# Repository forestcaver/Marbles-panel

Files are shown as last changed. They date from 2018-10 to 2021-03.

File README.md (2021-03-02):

# Marbles-Panel

1. My version of the marbles panel - bitmap, eagle files, gerbers
2. My spreadsheet to calibrate marbles and my version of settings.cc which includes my calibration data for my two modules.
3. Calibration document written by Bu Ma from some rough notes I sent - his are very clear instructions ! (Reproduced here by kind permission of Bu Ma !)
4. NOTE: When flashing the module make sure to erase flash first.
5. Added a mic803 supervisor, moved recom to the back of the pcb so it doesnt clash with the switch

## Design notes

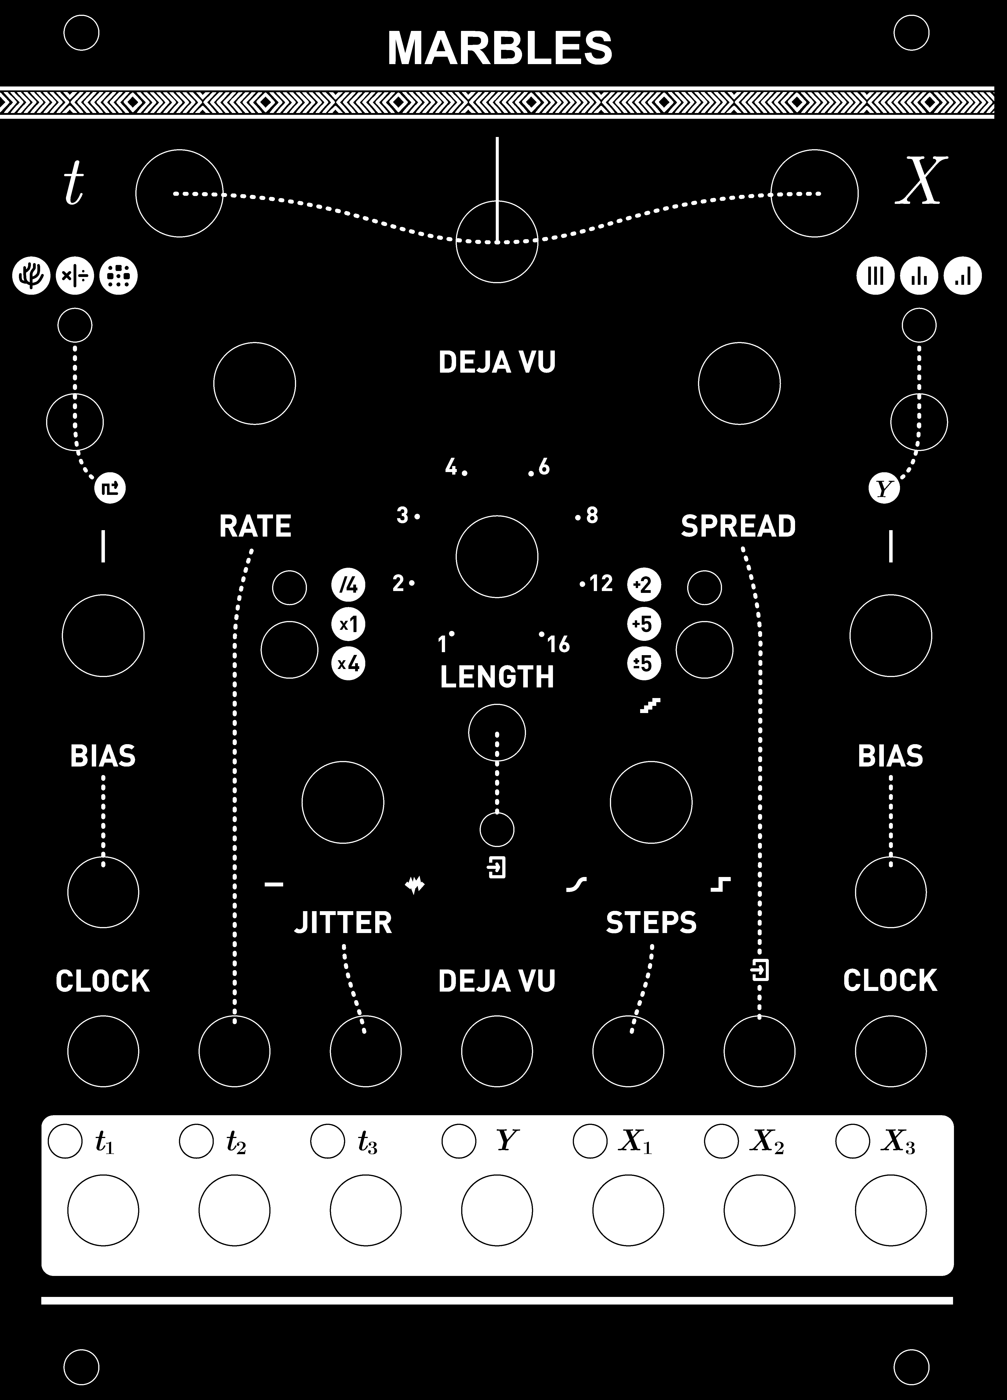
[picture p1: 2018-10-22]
marbles_v70_AJH3.bmp

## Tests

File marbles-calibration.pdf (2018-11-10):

## Marbles Calibration

Part 1: setting the module to output quantized voltages 1V and 3V.

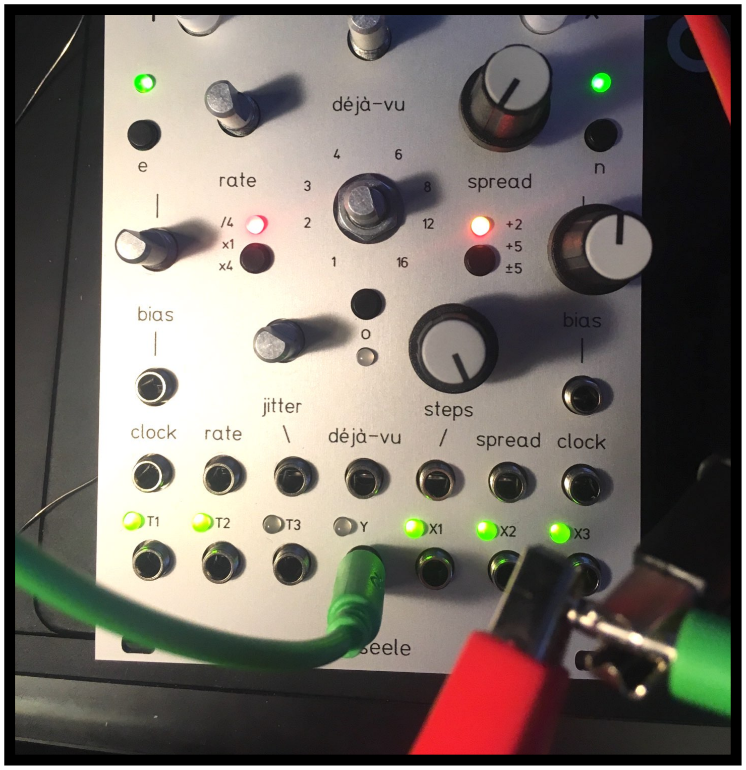
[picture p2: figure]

1. Connect the CV output X1 to a high count (ie 50000 count) multimeter (fig.1)
2. Set the voltage range (J) to +5V (orange LED).
3. Set (E) and (N) to green.
4. Turn the « Spread » knob fully counter-clockwise
5. Turn the « Steps » knob fully clockwise
6. Turn « bias » to select the octave, you need to find the closest value to 1V (You will probably find a value between 0.91 and 0.99). Then do the same for
3V.
7. Write down these values in
the corresponding cells of the spreadsheet (1V and 3V) and do the same thing for
the next CV outputs X2 and
X3.

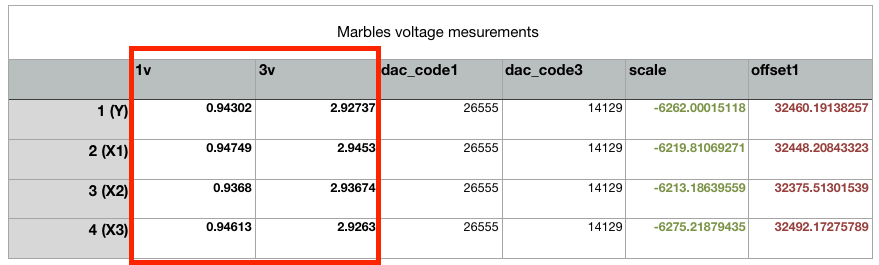
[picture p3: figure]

8. For the Y output : hold down the (N) button and turn the « Spread » knob fully counter-clockwise and the « Steps » knob fully clockwise. You will probably have to adjust the « rate » in order to « stabilize » this CV output while you read the voltage value.

Part 2: copying the voltage measurements to settings.cc, compiling and uploading the firmware.

1. Open the file named settings.cc in an editor. You will find the file in Mutable-dev-environment -> eurorack-modules -> Marbles

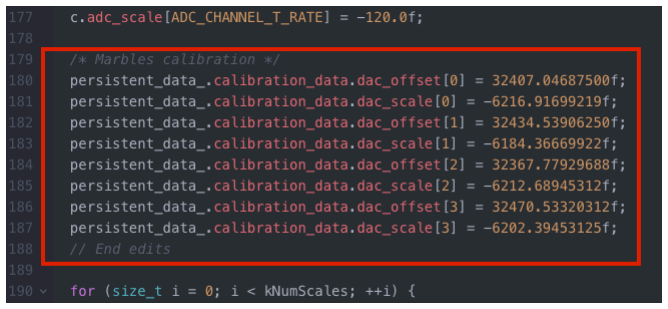
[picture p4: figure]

2. Copy and paste the values of
Scale and Offset from the
spreadsheet to settings.cc
(line 179). Don’t forget the « f » and make sure the
separator is a dot. [O] is Y
[1] is X1 etc.

### 3. Save the file, compile the

firmware and upload it to
the module.

Part 3: ADC calibration.

To calibrate the adc, long-press the rate and spread buttons. Feed 1v into rate input, press one of the two buttons, feed in 3v, press button, feed 1v into spread cv, press button and then feed 3v into spread cv, press button and the calibration is done.

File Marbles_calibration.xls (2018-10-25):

Table 1
 | 1v | 3v | dac_code1 | dac_code3 | scale | offset1 | offset2
1 | 0.94302 | 2.92737 | 26555 | 14129 | -6262.000151 | 32460.19138 | 32460.19138
2 | 0.94749 | 2.9453 | 26555 | 14129 | -6219.810693 | 32448.20843 | 32448.20843
3 | 0.9368 | 2.93674 | 26555 | 14129 | -6213.186396 | 32375.51302 | 32375.51302
4 | 0.94613 | 2.9263 | 26555 | 14129 | -6275.218794 | 32492.17276 | 32492.17276
 | 1v | 3v | dac_code1 | dac_code3 | scale | offset1 | offset2
1 | 0.94131 | 2.94005 | 26555 | 14129 | -6216.916657 | 32407.04582 | 32407.04582
2 | 0.95071 | 2.95997 | 26555 | 14129 | -6184.366384 | 32434.53896 | 32434.53896
3 | 0.93563 | 2.93573 | 26555 | 14129 | -6212.689366 | 32367.77855 | 32367.77855
4 | 0.95375 | 2.95717 | 26555 | 14129 | -6202.393906 | 32470.53319 | 32470.53319

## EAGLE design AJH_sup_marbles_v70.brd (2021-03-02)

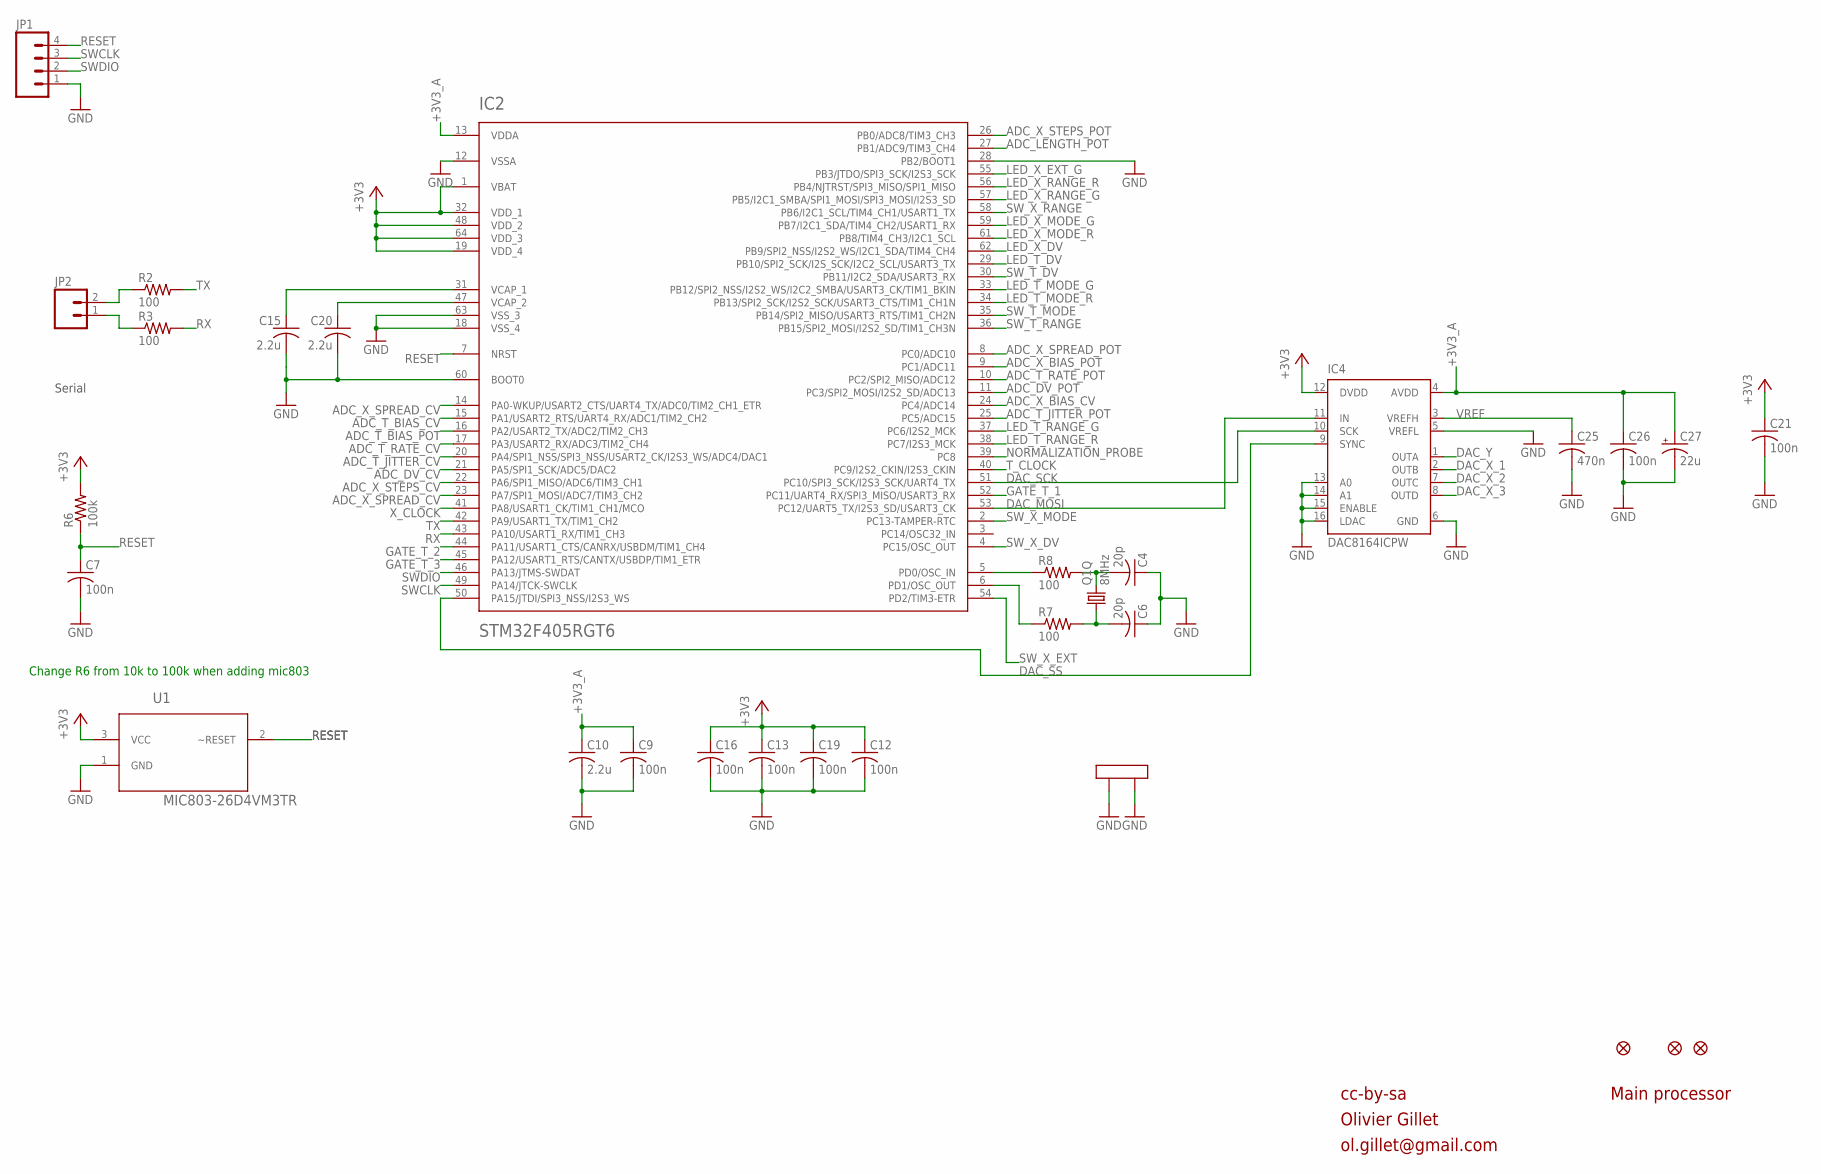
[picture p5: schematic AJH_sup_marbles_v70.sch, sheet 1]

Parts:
C4, C6: 20p; C0402
C7, C9, C12, C13, C16, C19, C21, C26: 100n; C0402
C10, C15, C20: 2.2u; C0805
C25: 470n; C0402
C27: 22u; PANASONIC_C
F1, F2, F3: FIDUCIAL1X2; FIDUCIAL-1X2
IC2: STM32F405RGT6; TQFP-10X10-64
IC4: DAC8164ICPW; SOP65P640X110-16N
JP1: M04PTH; 1X04
JP2: M02PTH; 1X02
Q1: 8MHz; CTS406
R2, R3, R7, R8: 100; R0402
R6: 100k; R0402
U1: MIC803-26D4VM3TR; SOT95P232X110-3N

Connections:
+3V3: C12.1, C13.1, C16.1, C19.1, C21.1, IC2.1 (VBAT), IC2.19 (VDD_4), IC2.32 (VDD_1), IC2.48 (VDD_2), IC2.64 (VDD_3), IC4.12 (DVDD), R6.2, U1.3 (VCC); also elsewhere on the board
+3V3_A: C9.1, C10.1, C26.1, C27.+, IC2.13 (VDDA), IC4.4 (AVDD); also elsewhere on the board
ADC_DV_CV: IC2.21 (PA5/SPI1_SCK/ADC5/DAC2); also elsewhere on the board
ADC_DV_POT: IC2.11 (PC3/SPI2_MOSI/I2S2_SD/ADC13); also elsewhere on the board
ADC_LENGTH_POT: IC2.27 (PB1/ADC9/TIM3_CH4); also elsewhere on the board
ADC_T_BIAS_CV: IC2.15 (PA1/USART2_RTS/UART4_RX/ADC1/TIM2_CH2); also elsewhere on the board
ADC_T_BIAS_POT: IC2.16 (PA2/USART2_TX/ADC2/TIM2_CH3); also elsewhere on the board
ADC_T_JITTER_CV: IC2.20 (PA4/SPI1_NSS/SPI3_NSS/USART2_CK/I2S3_WS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); also elsewhere on the board
ADC_T_JITTER_POT: IC2.25 (PC5/ADC15); also elsewhere on the board
ADC_T_RATE_CV: IC2.17 (PA3/USART2_RX/ADC3/TIM2_CH4); also elsewhere on the board
ADC_T_RATE_POT: IC2.10 (PC2/SPI2_MISO/ADC12); also elsewhere on the board
ADC_X_BIAS_CV: IC2.24 (PC4/ADC14); also elsewhere on the board
ADC_X_BIAS_POT: IC2.9 (PC1/ADC11); also elsewhere on the board
ADC_X_SPREAD_CV: IC2.14 (PA0-WKUP/USART2_CTS/UART4_TX/ADC0/TIM2_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), IC2.23 (PA7/SPI1_MOSI/ADC7/TIM3_CH2); also elsewhere on the board
ADC_X_SPREAD_POT: IC2.8 (PC0/ADC10); also elsewhere on the board
ADC_X_STEPS_CV: IC2.22 (PA6/SPI1_MISO/ADC6/TIM3_CH1); also elsewhere on the board
ADC_X_STEPS_POT: IC2.26 (PB0/ADC8/TIM3_CH3); also elsewhere on the board
DAC_MOSI: IC2.53 (PC12/UART5_TX/I2S3_SD/USART3_CK), IC4.11 (IN)
DAC_SCK: IC2.51 (PC10/SPI3_SCK/I2S3_SCK/UART4_TX), IC4.10 (SCK)
DAC_SS: IC2.50 (PA15/JTDI/SPI3_NSS/I2S3_WS), IC4.9 (SYNC)
DAC_X_1: IC4.2 (OUTB); also elsewhere on the board
DAC_X_2: IC4.7 (OUTC); also elsewhere on the board
DAC_X_3: IC4.8 (OUTD); also elsewhere on the board
DAC_Y: IC4.1 (OUTA); also elsewhere on the board
GATE_T_1: IC2.52 (PC11/UART4_RX/SPI3_MISO/USART3_RX); also elsewhere on the board
GATE_T_2: IC2.44 (PA11/USART1_CTS/CANRX/USBDM/TIM1_CH4); also elsewhere on the board
GATE_T_3: IC2.45 (PA12/USART1_RTS/CANTX/USBDP/TIM1_ETR); also elsewhere on the board
GND: C4.1, C6.1, C7.2, C9.2, C10.2, C12.2, C13.2, C15.2, C16.2, C19.2, C20.2, C21.2, C25.2, C26.2, C27.-, IC2.12 (VSSA), IC2.18 (VSS_4), IC2.28 (PB2/BOOT1), IC2.60 (BOOT0), IC2.63 (VSS_3), IC4.5 (VREFL), IC4.6 (GND), IC4.13 (A0), IC4.14 (A1), IC4.15 (ENABLE), IC4.16 (LDAC), JP1.1, Q1.2 (LID1), Q1.4 (LID2), U1.1 (GND); also elsewhere on the board
LED_T_DV: IC2.29 (PB10/SPI2_SCK/I2S_SCK/I2C2_SCL/USART3_TX); also elsewhere on the board
LED_T_MODE_G: IC2.33 (PB12/SPI2_NSS/I2S2_WS/I2C2_SMBA/USART3_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); also elsewhere on the board
LED_T_MODE_R: IC2.34 (PB13/SPI2_SCK/I2S2_SCK/USART3_CTS/TIM1_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); also elsewhere on the board
LED_T_RANGE_G: IC2.37 (PC6/I2S2_MCK); also elsewhere on the board
LED_T_RANGE_R: IC2.38 (PC7/I2S3_MCK); also elsewhere on the board
LED_X_DV: IC2.62 (PB9/SPI2_NSS/I2S2_WS/I2C1_SDA/TIM4_CH4); also elsewhere on the board
LED_X_EXT_G: IC2.55 (PB3/JTDO/SPI3_SCK/I2S3_SCK); also elsewhere on the board
LED_X_MODE_G: IC2.59 (PB7/I2C1_SDA/TIM4_CH2/USART1_RX); also elsewhere on the board
LED_X_MODE_R: IC2.61 (PB8/TIM4_CH3/I2C1_SCL); also elsewhere on the board
LED_X_RANGE_G: IC2.57 (PB5/I2C1_SMBA/SPI1_MOSI/SPI3_MOSI/I2S3_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); also elsewhere on the board
LED_X_RANGE_R: IC2.56 (PB4/NJTRST/SPI3_MISO/SPI1_MISO); also elsewhere on the board
unnamed: IC2.6 (PD1/OSC_OUT), R7.1
unnamed: IC2.5 (PD0/OSC_IN), R8.1
unnamed: C20.1, IC2.47 (VCAP_2)
unnamed: C15.1, IC2.31 (VCAP_1)
unnamed: JP2.2, R2.1
unnamed: JP2.1, R3.1
unnamed: C4.2, Q1.3 (2), R8.2
unnamed: C6.2, Q1.1, R7.2
NORMALIZATION_PROBE: IC2.39 (PC8); also elsewhere on the board
RESET: C7.1, IC2.7 (NRST), JP1.4, R6.1, U1.2 (~RESET)
RX: IC2.43 (PA10/USART1_RX/TIM1_CH3), R3.2
SWCLK: IC2.49 (PA14/JTCK-SWCLK), JP1.3
SWDIO: IC2.46 (PA13/JTMS-SWDAT), JP1.2
SW_T_DV: IC2.30 (PB11/I2C2_SDA/USART3_RX); also elsewhere on the board
SW_T_MODE: IC2.35 (PB14/SPI2_MISO/USART3_RTS/TIM1_CH2N); also elsewhere on the board
SW_T_RANGE: IC2.36 (PB15/SPI2_MOSI/I2S2_SD/TIM1_CH3N); also elsewhere on the board
SW_X_DV: IC2.4 (PC15/OSC_OUT); also elsewhere on the board
SW_X_EXT: IC2.54 (PD2/TIM3-ETR); also elsewhere on the board
SW_X_MODE: IC2.2 (PC13-TAMPER-RTC); also elsewhere on the board
SW_X_RANGE: IC2.58 (PB6/I2C1_SCL/TIM4_CH1/USART1_TX); also elsewhere on the board
TX: IC2.42 (PA9/USART1_TX/TIM1_CH2), R2.2
T_CLOCK: IC2.40 (PC9/I2S2_CKIN/I2S3_CKIN); also elsewhere on the board
VREF: C25.1, IC4.3 (VREFH); also elsewhere on the board
X_CLOCK: IC2.41 (PA8/USART1_CK/TIM1_CH1/MCO); also elsewhere on the board

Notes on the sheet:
cc-by-sa
Olivier Gillet
ol.gillet@gmail.com
Main processor
Serial
Change R6 from 10k to 100k when adding mic803

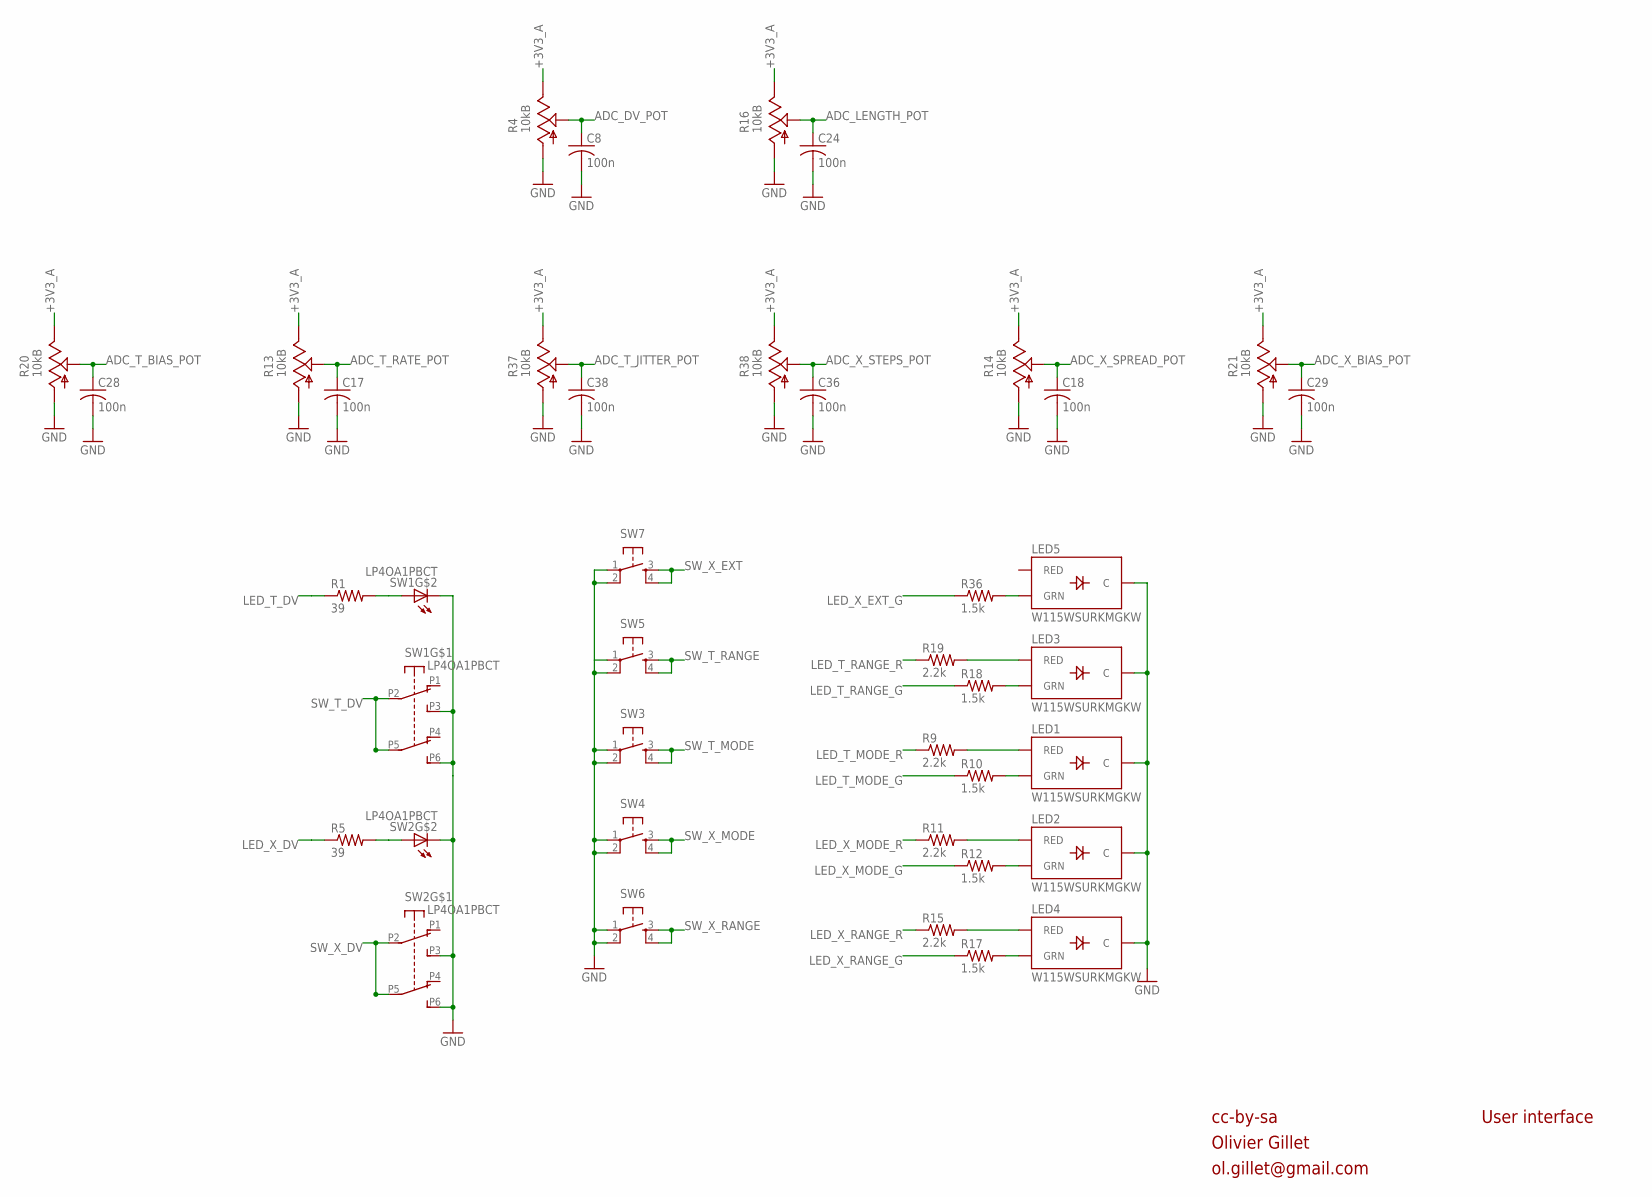
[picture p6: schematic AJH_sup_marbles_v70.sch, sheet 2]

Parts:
C8, C17, C18, C24, C28, C29, C36, C38: 100n; C0402
LED1, LED2, LED3, LED4, LED5: W115WSURKMGKW; LED-BICOLOR-THROUGHHOLE-2.54
R1, R5: 39; R0402
R4, R13, R14, R16, R20, R21, R37, R38: 10kB; ALPS_POT_VERTICAL_PS
R9, R11, R15, R19: 2.2k; R0402
R10, R12, R17, R18, R36: 1.5k; R0402
SW1, SW2: LP4OA1PBCT
SW3, SW4, SW5, SW6, SW7: TAC_SWITCHPTH; TACTILE-PTH

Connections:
+3V3_A: R4.P$1 (E), R13.P$1 (E), R14.P$1 (E), R16.P$1 (E), R20.P$1 (E), R21.P$1 (E), R37.P$1 (E), R38.P$1 (E); also elsewhere on the board
ADC_DV_POT: C8.1, R4.P$2 (S); also elsewhere on the board
ADC_LENGTH_POT: C24.1, R16.P$2 (S); also elsewhere on the board
ADC_T_BIAS_POT: C28.1, R20.P$2 (S); also elsewhere on the board
ADC_T_JITTER_POT: C38.1, R37.P$2 (S); also elsewhere on the board
ADC_T_RATE_POT: C17.1, R13.P$2 (S); also elsewhere on the board
ADC_X_BIAS_POT: C29.1, R21.P$2 (S); also elsewhere on the board
ADC_X_SPREAD_POT: C18.1, R14.P$2 (S); also elsewhere on the board
ADC_X_STEPS_POT: C36.1, R38.P$2 (S); also elsewhere on the board
GND: C8.2, C17.2, C18.2, C24.2, C28.2, C29.2, C36.2, C38.2, LED1.2 (C), LED2.2 (C), LED3.2 (C), LED4.2 (C), LED5.2 (C), R4.P$3 (A), R13.P$3 (A), R14.P$3 (A), R16.P$3 (A), R20.P$3 (A), R21.P$3 (A), R37.P$3 (A), R38.P$3 (A), SW1.L2, SW1.P3 (A3), SW1.P6 (B3), SW2.L2, SW2.P3 (A3), SW2.P6 (B3), SW3.1, SW3.2, SW4.1, SW4.2, SW5.1, SW5.2, SW6.1, SW6.2, SW7.1, SW7.2; also elsewhere on the board
LED_T_DV: R1.1; also elsewhere on the board
LED_T_MODE_G: R10.1; also elsewhere on the board
LED_T_MODE_R: R9.1; also elsewhere on the board
LED_T_RANGE_G: R18.1; also elsewhere on the board
LED_T_RANGE_R: R19.1; also elsewhere on the board
LED_X_DV: R5.1; also elsewhere on the board
LED_X_EXT_G: R36.1; also elsewhere on the board
LED_X_MODE_G: R12.1; also elsewhere on the board
LED_X_MODE_R: R11.1; also elsewhere on the board
LED_X_RANGE_G: R17.1; also elsewhere on the board
LED_X_RANGE_R: R15.1; also elsewhere on the board
unnamed: R1.2, SW1.L1
unnamed: R5.2, SW2.L1
unnamed: LED3.3 (RED), R19.2
unnamed: LED3.1 (GRN), R18.2
unnamed: LED1.3 (RED), R9.2
unnamed: LED2.3 (RED), R11.2
unnamed: LED2.1 (GRN), R12.2
unnamed: LED4.3 (RED), R15.2
unnamed: LED1.1 (GRN), R10.2
unnamed: LED4.1 (GRN), R17.2
unnamed: LED5.1 (GRN), R36.2
SW_T_DV: SW1.P2 (A2), SW1.P5 (B2); also elsewhere on the board
SW_T_MODE: SW3.3, SW3.4; also elsewhere on the board
SW_T_RANGE: SW5.3, SW5.4; also elsewhere on the board
SW_X_DV: SW2.P2 (A2), SW2.P5 (B2); also elsewhere on the board
SW_X_EXT: SW7.3, SW7.4; also elsewhere on the board
SW_X_MODE: SW4.3, SW4.4; also elsewhere on the board
SW_X_RANGE: SW6.3, SW6.4; also elsewhere on the board

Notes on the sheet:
cc-by-sa
Olivier Gillet
ol.gillet@gmail.com
User interface

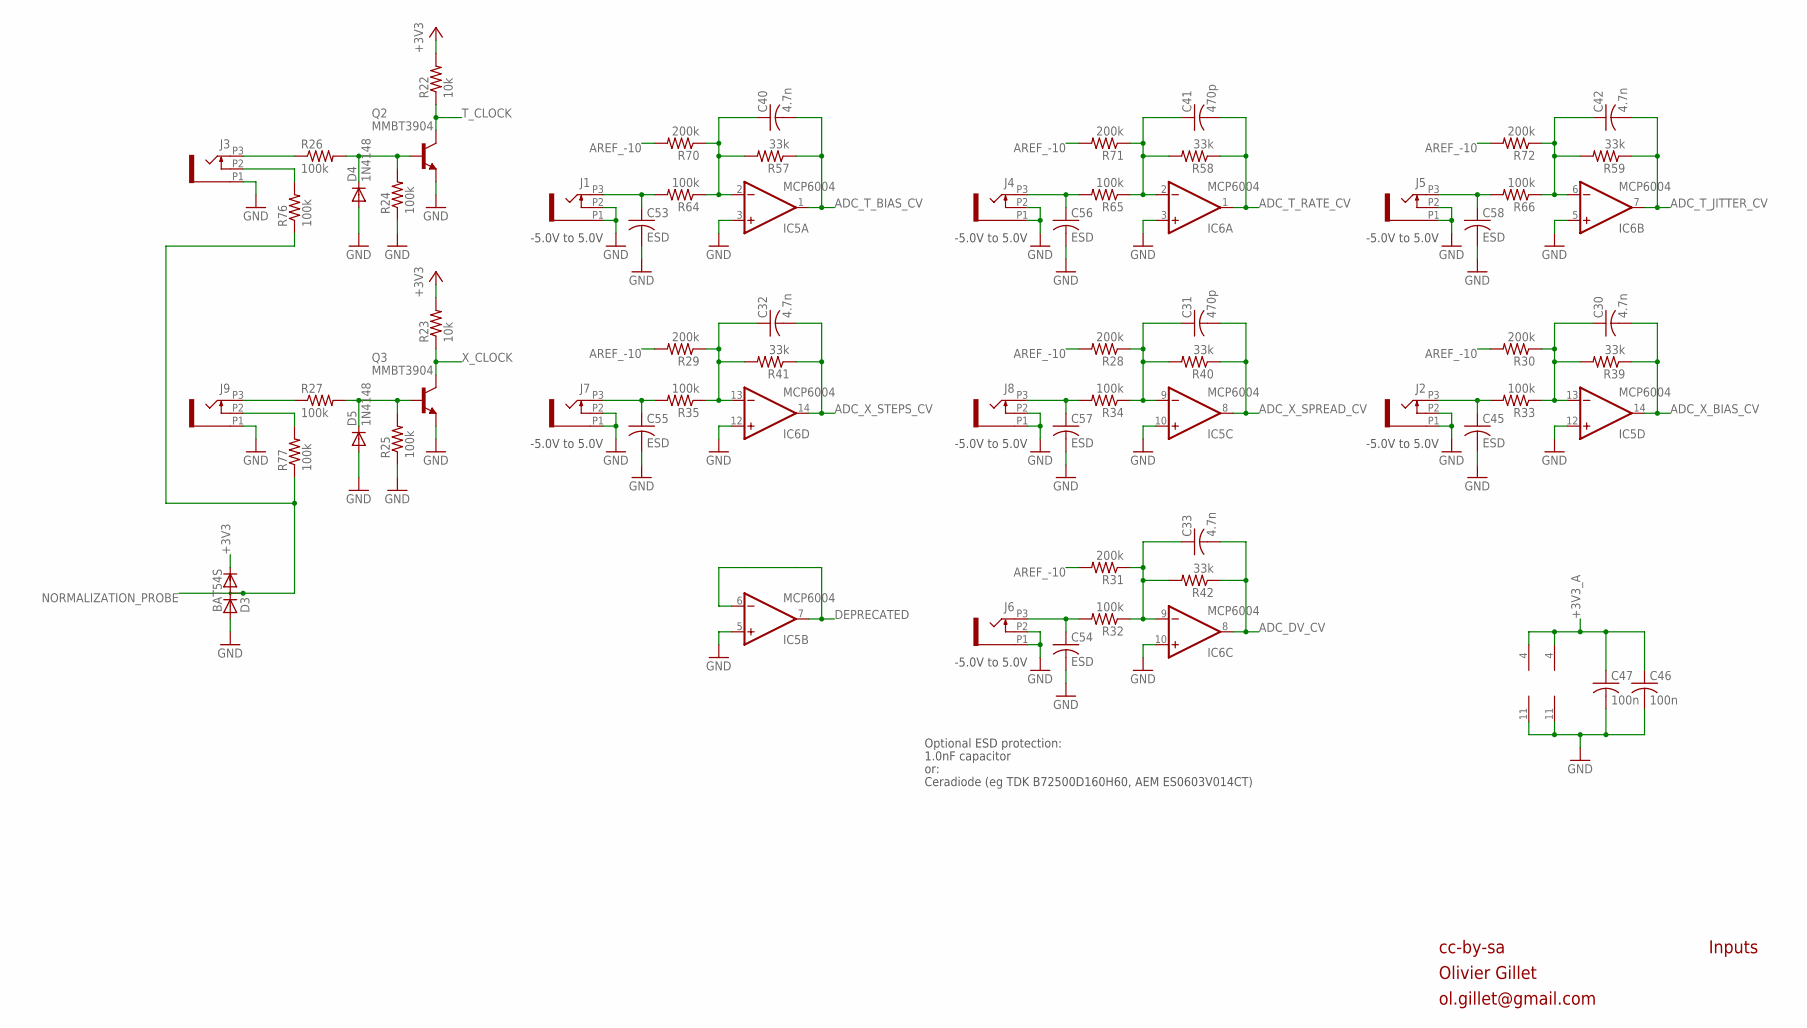
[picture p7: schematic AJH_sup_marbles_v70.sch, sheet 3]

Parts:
C30, C32, C33, C40, C42: 4.7n; C0402
C31, C41: 470p; C0402
C45, C53, C54, C55, C56, C57, C58: ESD; C0603
C46, C47: 100n; C0402
D3: BAT54S; SOT23
D4, D5: 1N4148; SOD523
IC5, IC6: MCP6004; TSSOP14_065
J1, J2, J3, J4, J5, J6, J7, J8, J9: PJ301_THONKICONN6; WQP_PJ_301M6
Q2, Q3: MMBT3904; SOT23-BEC
R22, R23: 10k; R0402
R24, R25, R26, R27, R32, R33, R34, R35, R64, R65, R66, R76, R77: 100k; R0402
R28, R29, R30, R31, R70, R71, R72: 200k; R0402
R39, R40, R41, R42, R57, R58, R59: 33k; R0402

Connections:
+3V3: D3.2 (C), R22.2, R23.2; also elsewhere on the board
+3V3_A: C46.1, C47.1, IC5.4 (V+), IC6.4 (V+); also elsewhere on the board
ADC_DV_CV: C33.2, IC6.8 (OUT), R42.1; also elsewhere on the board
ADC_T_BIAS_CV: C40.2, IC5.1 (OUT), R57.1; also elsewhere on the board
ADC_T_JITTER_CV: C42.2, IC6.7 (OUT), R59.1; also elsewhere on the board
ADC_T_RATE_CV: C41.2, IC6.1 (OUT), R58.1; also elsewhere on the board
ADC_X_BIAS_CV: C30.2, IC5.14 (OUT), R39.1; also elsewhere on the board
ADC_X_SPREAD_CV: C31.2, IC5.8 (OUT), R40.1; also elsewhere on the board
ADC_X_STEPS_CV: C32.2, IC6.14 (OUT), R41.1; also elsewhere on the board
AREF_-10: R28.2, R29.2, R30.2, R31.2, R70.2, R71.2, R72.2; also elsewhere on the board
DEPRECATED: IC5.6 (-IN), IC5.7 (OUT)
GND: C45.2, C46.2, C47.2, C53.2, C54.2, C55.2, C56.2, C57.2, C58.2, D3.1 (A), D4.A, D5.A, IC5.3 (+IN), IC5.5 (+IN), IC5.10 (+IN), IC5.11 (V-), IC5.12 (+IN), IC6.3 (+IN), IC6.5 (+IN), IC6.10 (+IN), IC6.11 (V-), IC6.12 (+IN), J1.P1 (1), J1.P2 (2), J2.P1 (1), J2.P2 (2), J3.P1 (1), J4.P1 (1), J4.P2 (2), J5.P1 (1), J5.P2 (2), J6.P1 (1), J6.P2 (2), J7.P1 (1), J7.P2 (2), J8.P1 (1), J8.P2 (2), J9.P1 (1), Q2.E, Q3.E, R24.1, R25.1; also elsewhere on the board
MORPH_IN: C53.1, J1.P3 (3), R64.2
MORPH_IN1: C55.1, J7.P3 (3), R35.2
MORPH_IN3: C56.1, J4.P3 (3), R65.2
MORPH_IN4: C57.1, J8.P3 (3), R34.2
MORPH_IN5: C54.1, J6.P3 (3), R32.2
MORPH_IN6: C58.1, J5.P3 (3), R66.2
MORPH_IN7: C45.1, J2.P3 (3), R33.2
unnamed: C41.1, IC6.2 (-IN), R58.2, R65.1, R71.1
unnamed: C40.1, IC5.2 (-IN), R57.2, R64.1, R70.1
unnamed: C42.1, IC6.6 (-IN), R59.2, R66.1, R72.1
unnamed: C31.1, IC5.9 (-IN), R28.1, R34.1, R40.2
unnamed: C30.1, IC5.13 (-IN), R30.1, R33.1, R39.2
unnamed: C32.1, IC6.13 (-IN), R29.1, R35.1, R41.2
unnamed: C33.1, IC6.9 (-IN), R31.1, R32.1, R42.2
unnamed: J9.P3 (3), R27.1
unnamed: J9.P2 (2), R77.2
unnamed: J3.P2 (2), R76.2
unnamed: D4.C, Q2.B, R24.2, R26.2
unnamed: D5.C, Q3.B, R25.2, R27.2
unnamed: J3.P3 (3), R26.1
NORMALIZATION_PROBE: D3.3 (AC), R76.1, R77.1; also elsewhere on the board
T_CLOCK: Q2.C, R22.1; also elsewhere on the board
X_CLOCK: Q3.C, R23.1; also elsewhere on the board

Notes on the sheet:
cc-by-sa
Olivier Gillet
ol.gillet@gmail.com
Inputs
-5.0V to 5.0V
Optional ESD protection:
1.0nF capacitor
or:
Ceradiode (eg TDK B72500D160H60, AEM ES0603V014CT)

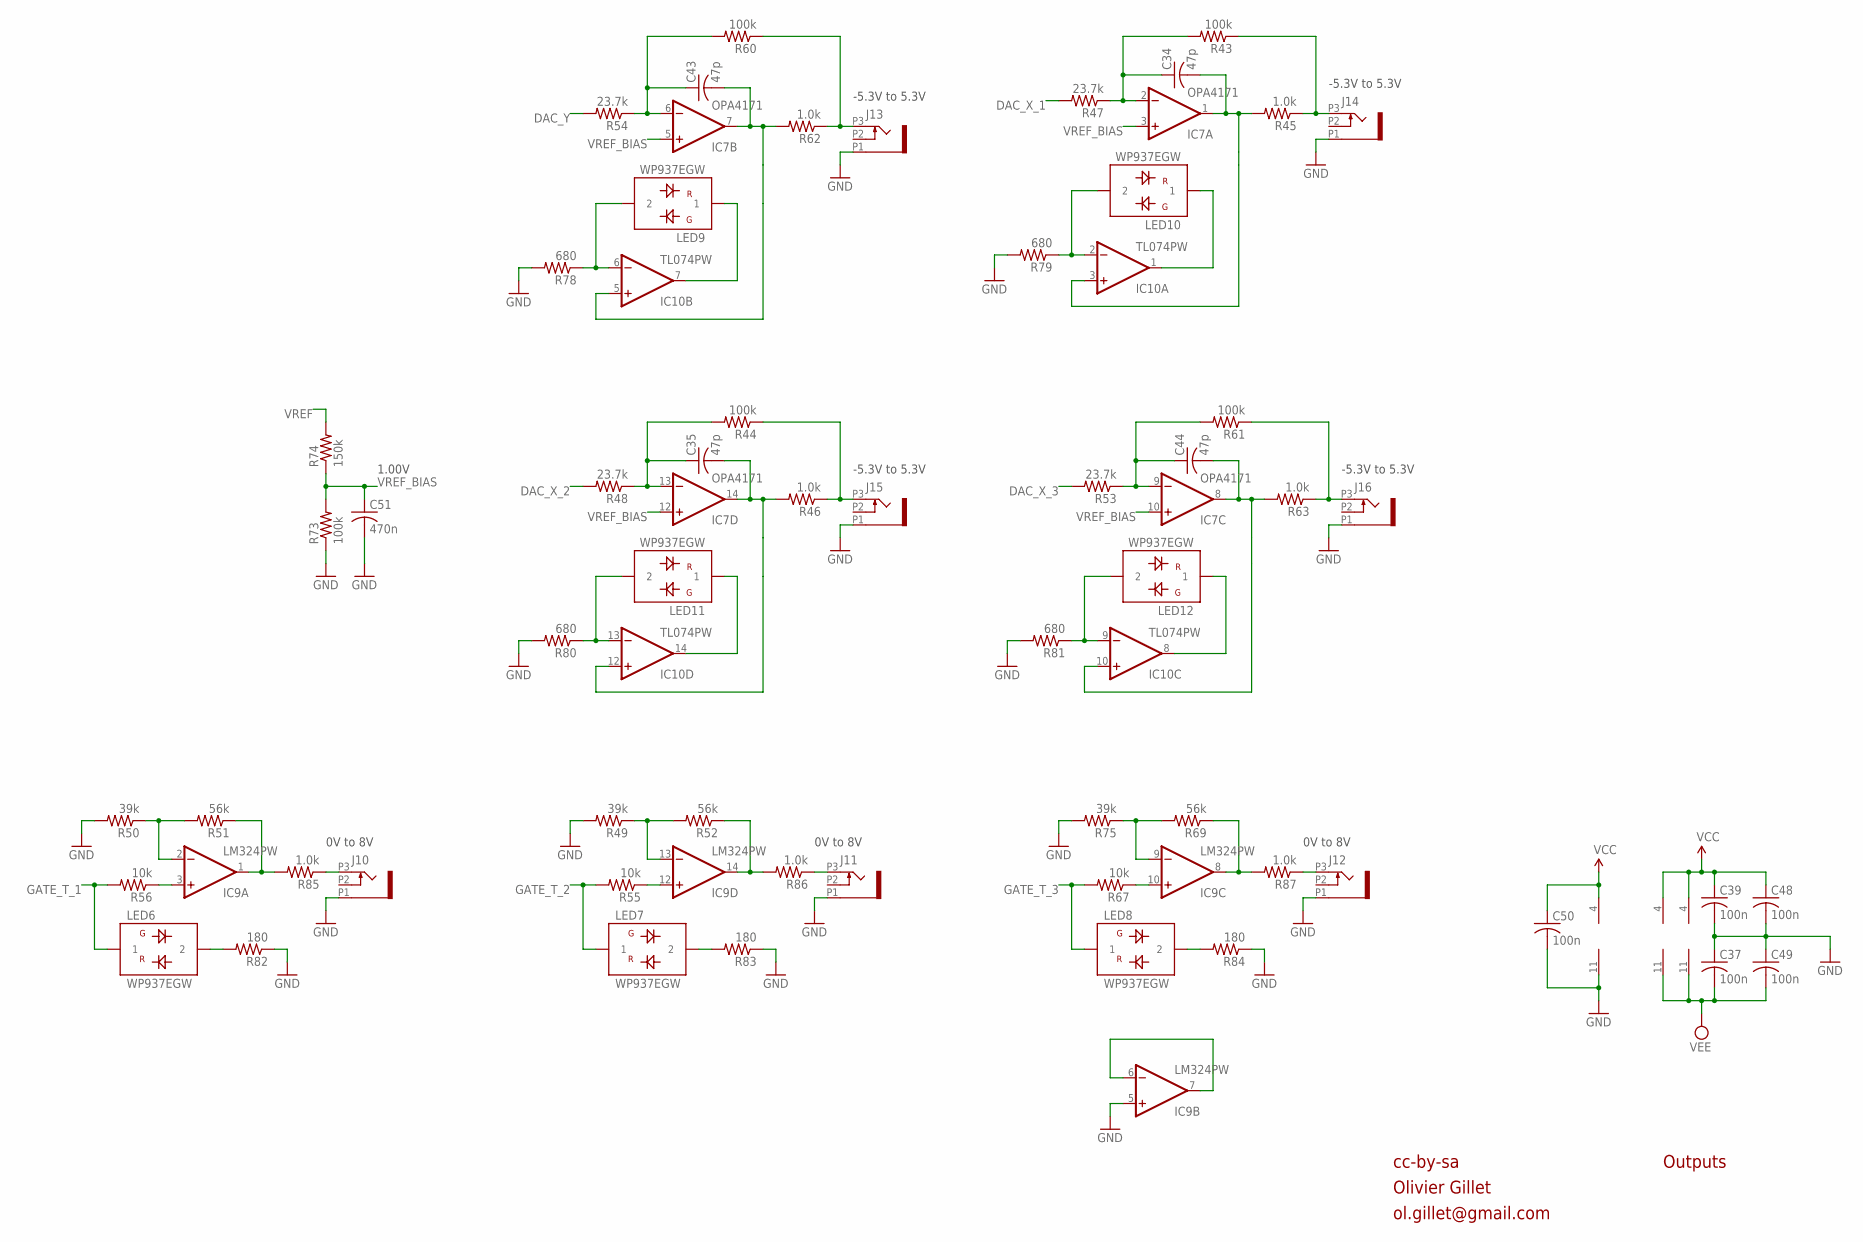
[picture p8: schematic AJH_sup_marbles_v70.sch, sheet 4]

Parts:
C34, C35, C43, C44: 47p; C0402
C37, C39, C48, C49, C50: 100n; C0402
C51: 470n; C0402
IC7: OPA4171; TSSOP14_065
IC9: LM324PW; TSSOP14_065
IC10: TL074PW; TSSOP14_065
J10, J11, J12, J13, J14, J15, J16: PJ301_THONKICONN6; WQP_PJ_301M6
LED6, LED7, LED8, LED9, LED10, LED11, LED12: WP937EGW; LED3MM
R43, R44, R60, R61, R73: 100k; R0402
R45, R46, R62, R63, R85, R86, R87: 1.0k; R0603
R47, R48, R53, R54: 23.7k; R0402
R49, R50, R75: 39k; R0402
R51, R52, R69: 56k; R0402
R55, R56, R67: 10k; R0402
R74: 150k; R0402
R78, R79, R80, R81: 680; R0402
R82, R83, R84: 180; R0402

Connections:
DAC_X_1: R47.2; also elsewhere on the board
DAC_X_2: R48.2; also elsewhere on the board
DAC_X_3: R53.2; also elsewhere on the board
DAC_Y: R54.2; also elsewhere on the board
GATE_T_1: LED6.1, R56.2; also elsewhere on the board
GATE_T_2: LED7.1, R55.2; also elsewhere on the board
GATE_T_3: LED8.1, R67.2; also elsewhere on the board
GND: C37.1, C39.2, C48.2, C49.1, C50.2, C51.2, IC9.5 (+IN), IC9.11 (V-), J10.P1 (1), J11.P1 (1), J12.P1 (1), J13.P1 (1), J14.P1 (1), J15.P1 (1), J16.P1 (1), R49.2, R50.2, R73.1, R75.2, R78.2, R79.2, R80.2, R81.2, R82.1, R83.1, R84.1; also elsewhere on the board
unnamed: IC9.12 (+IN), R55.1
unnamed: IC9.1 (OUT), R51.1, R85.2
unnamed: J10.P3 (3), R85.1
unnamed: IC9.2 (-IN), R50.1, R51.2
unnamed: LED6.2, R82.2
unnamed: IC9.3 (+IN), R56.1
unnamed: IC9.6 (-IN), IC9.7 (OUT)
unnamed: IC9.14 (OUT), R52.1, R86.2
unnamed: IC9.13 (-IN), R49.1, R52.2
unnamed: IC9.10 (+IN), R67.1
unnamed: IC9.8 (OUT), R69.1, R87.2
unnamed: J11.P3 (3), R86.1
unnamed: J12.P3 (3), R87.1
unnamed: IC9.9 (-IN), R69.2, R75.1
unnamed: LED7.2, R83.2
unnamed: C43.2, IC7.7 (OUT), IC10.5 (+IN), R62.2
unnamed: LED8.2, R84.2
unnamed: J15.P3 (3), R44.1, R46.1
unnamed: J13.P3 (3), R60.1, R62.1
unnamed: C35.1, IC7.13 (-IN), R44.2, R48.1
unnamed: J16.P3 (3), R61.1, R63.1
unnamed: C44.1, IC7.9 (-IN), R53.1, R61.2
unnamed: C34.1, IC7.2 (-IN), R43.2, R47.1
unnamed: C43.1, IC7.6 (-IN), R54.1, R60.2
unnamed: J14.P3 (3), R43.1, R45.1
unnamed: IC10.6 (-IN), LED9.2, R78.1
unnamed: IC10.7 (OUT), LED9.1
unnamed: C34.2, IC7.1 (OUT), IC10.3 (+IN), R45.2
unnamed: IC10.2 (-IN), LED10.2, R79.1
unnamed: IC10.1 (OUT), LED10.1
unnamed: C35.2, IC7.14 (OUT), IC10.12 (+IN), R46.2
unnamed: IC10.13 (-IN), LED11.2, R80.1
unnamed: IC10.14 (OUT), LED11.1
unnamed: C44.2, IC7.8 (OUT), IC10.10 (+IN), R63.2
unnamed: IC10.9 (-IN), LED12.2, R81.1
unnamed: IC10.8 (OUT), LED12.1
VCC: C39.1, C48.1, C50.1, IC7.4 (V+), IC9.4 (V+), IC10.4 (V+); also elsewhere on the board
VEE: C37.2, C49.2, IC7.11 (V-), IC10.11 (V-); also elsewhere on the board
VREF: R74.2; also elsewhere on the board
VREF_BIAS: C51.1, IC7.3 (+IN), IC7.5 (+IN), IC7.10 (+IN), IC7.12 (+IN), R73.2, R74.1

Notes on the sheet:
-5.3V to 5.3V
0V to 8V
cc-by-sa
Olivier Gillet
ol.gillet@gmail.com
Outputs
1.00V

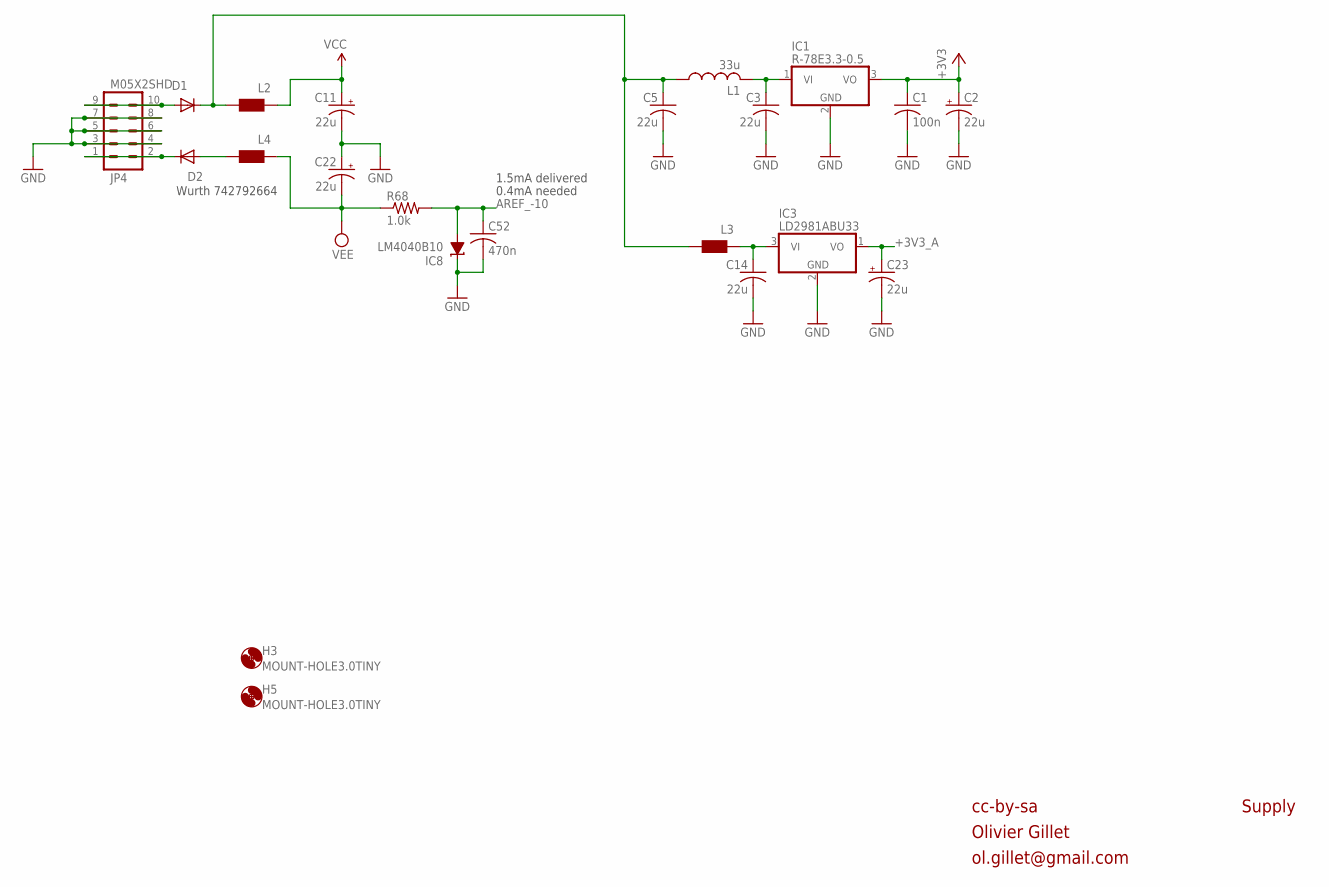
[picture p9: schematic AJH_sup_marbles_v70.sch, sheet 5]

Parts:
C1: 100n; C0402
C2, C11, C22, C23: 22u; PANASONIC_C
C3, C5, C14: 22u; C1206
C52: 470n; C0402
D1, D2: 1N5819HW; SOD123
H3, H5: MOUNT-HOLE3.0TINY; 3,0TINY
IC1: R-78E3.3-0.5; WE78
IC3: LD2981ABU33; SOT89
IC8: LM4040B10; DBZ_R-PDSO-G3
JP4: M05X2SHD; 2X5-SHROUDED
L1: 33u; L2012C
L2, L3, L4: WE-CBF_0603; 0603
R68: 1.0k; R0402

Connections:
+3V3: C1.1, C2.+, IC1.3 (VO); also elsewhere on the board
+3V3_A: C23.+, IC3.1 (VO); also elsewhere on the board
AREF_-10: C52.1, IC8.2 (A), R68.2; also elsewhere on the board
GND: C1.2, C2.-, C3.2, C5.2, C11.-, C14.2, C22.+, C23.-, C52.2, IC1.2 (GND), IC3.2 (GND), IC8.1 (C), JP4.3, JP4.4, JP4.5, JP4.6, JP4.7, JP4.8; also elsewhere on the board
unnamed: C14.1, IC3.3 (VI), L3.1
unnamed: C5.1, D1.C, L1.1, L2.2, L3.2
unnamed: D2.A, L4.2
unnamed: C3.1, IC1.1 (VI), L1.2
unnamed: D1.A, JP4.9, JP4.10
unnamed: D2.C, JP4.1, JP4.2
VCC: C11.+, L2.1; also elsewhere on the board
VEE: C22.-, L4.1, R68.1; also elsewhere on the board

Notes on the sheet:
0.4mA needed
cc-by-sa
Olivier Gillet
ol.gillet@gmail.com
Supply
Wurth 742792664
1.5mA delivered

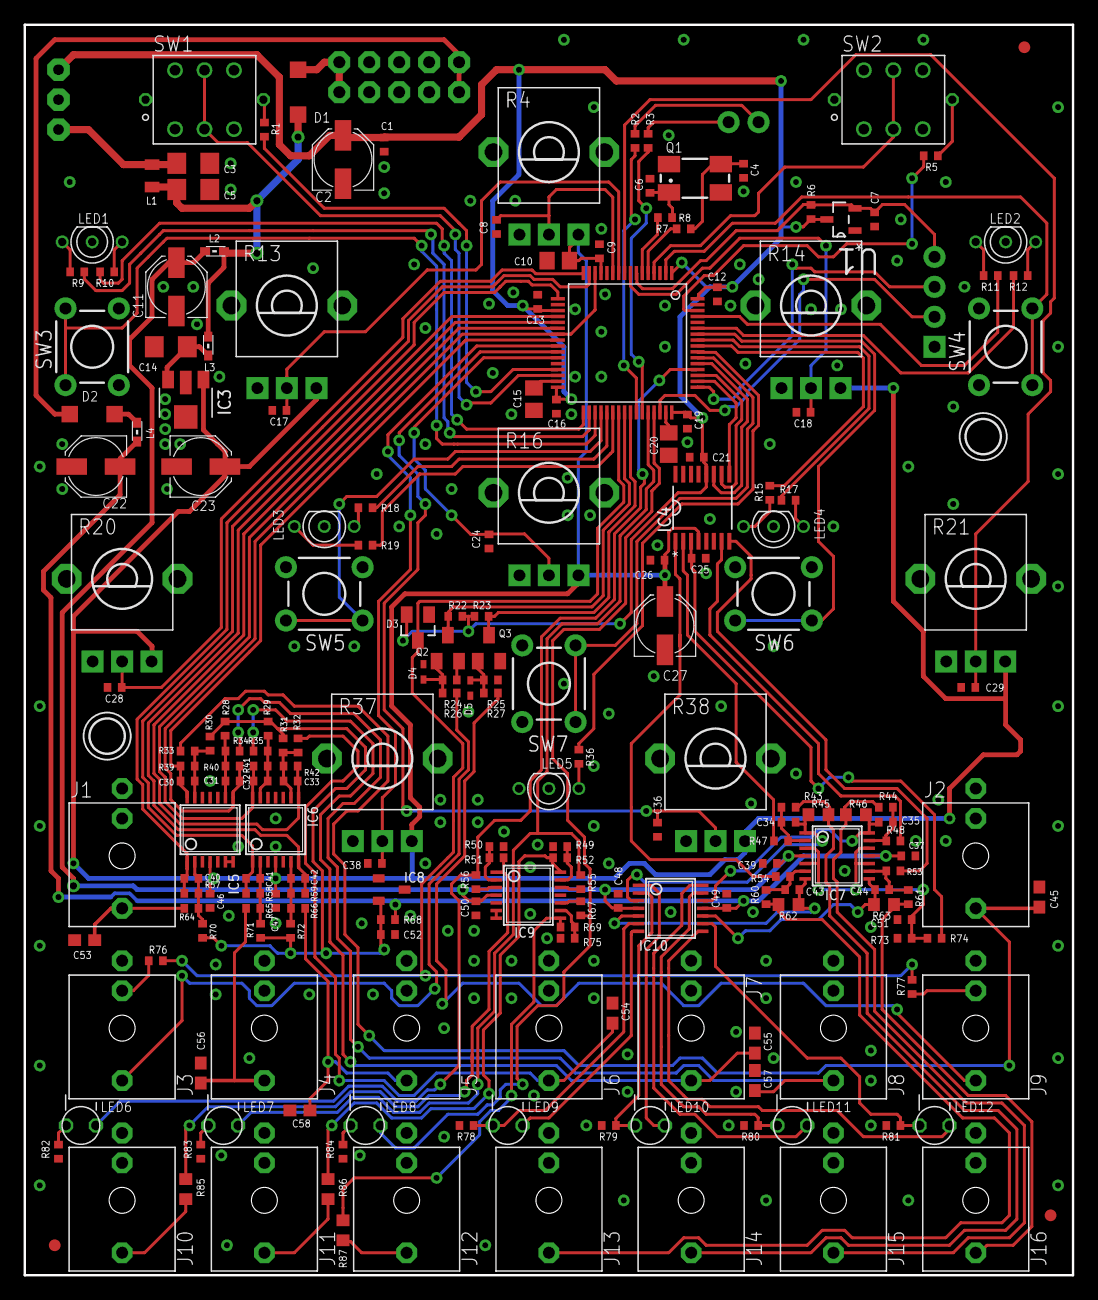
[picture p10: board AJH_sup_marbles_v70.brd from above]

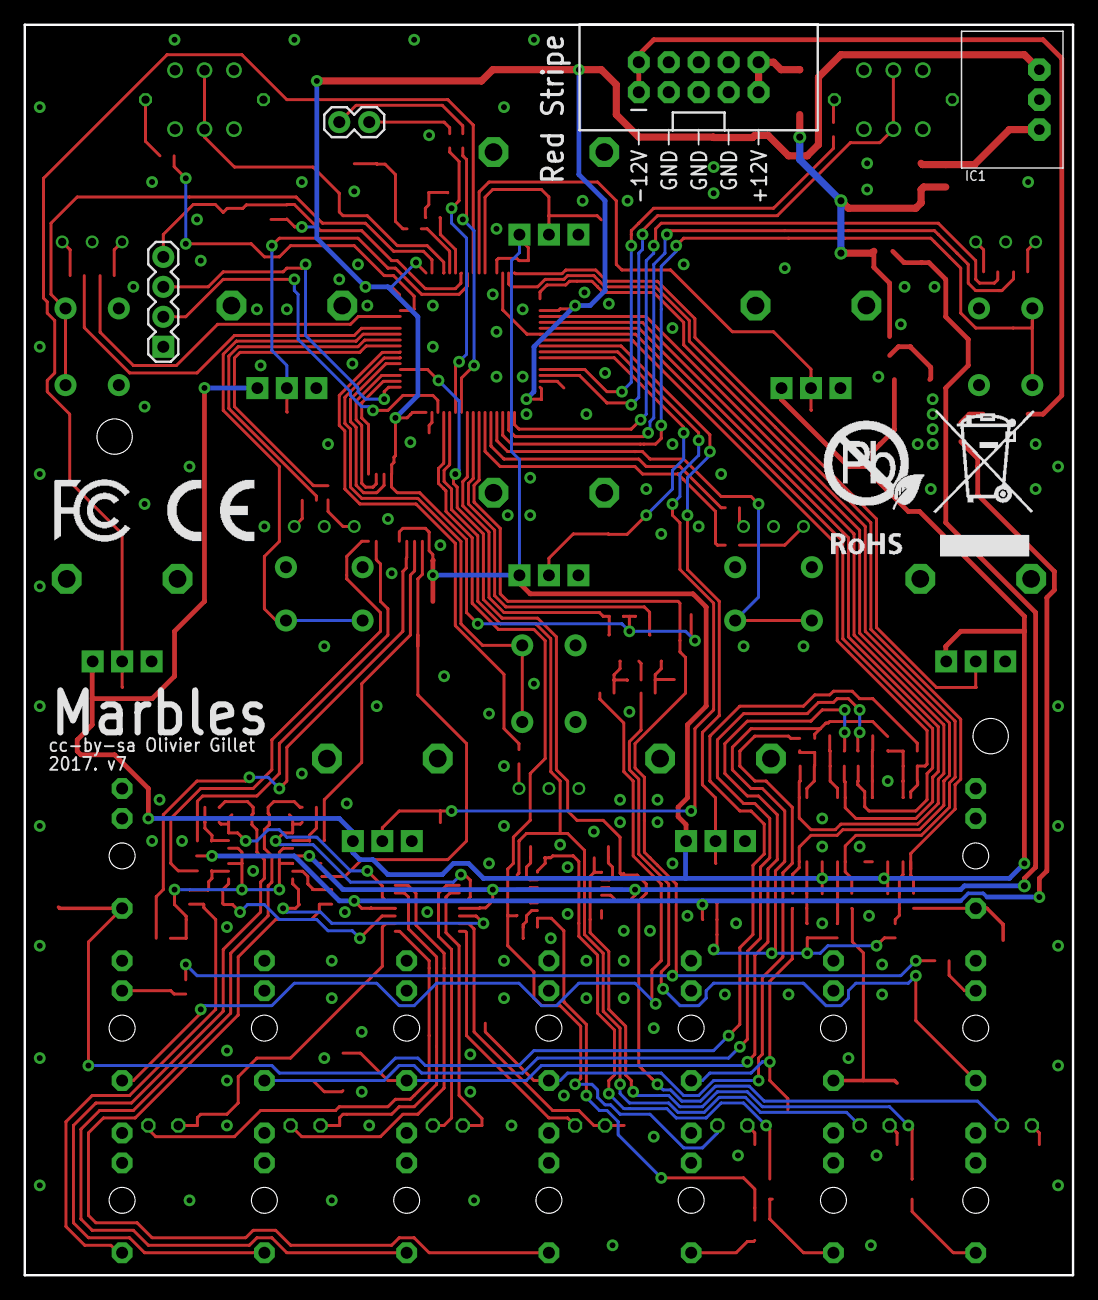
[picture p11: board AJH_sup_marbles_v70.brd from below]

Board: 2 copper layers, 88.9 x 106.0 mm, 214 parts (7 on the bottom side), 141 nets.

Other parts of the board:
U$2: ROHS_BIG
U$4: CE_MEDIUM
U$5: FCC_MEDIUM

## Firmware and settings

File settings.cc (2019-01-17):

// Copyright 2015 Olivier Gillet.
//
// Author: Olivier Gillet (ol.gillet@gmail.com)
//
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
// See http://creativecommons.org/licenses/MIT/ for more information.
//
// -----------------------------------------------------------------------------
//
// Settings storage.

#include "marbles/settings.h"

#include <algorithm>

#include "stmlib/system/storage.h"

namespace marbles {

using namespace std;

const Scale preset_scales[6] = {
  // C major
  {
    1.0f,
    12,
    {
      { 0.0000f, 255 },  // C
      { 0.0833f, 16 },   // C#
      { 0.1667f, 96 },   // D
      { 0.2500f, 24 },   // D#
      { 0.3333f, 128 },  // E
      { 0.4167f, 64 },   // F
      { 0.5000f, 8 },    // F#
      { 0.5833f, 192 },  // G
      { 0.6667f, 16 },   // G#
      { 0.7500f, 96 },   // A
      { 0.8333f, 24 },   // A#
      { 0.9167f, 128 },  // B
    }
  },
  
  // C minor
  {
    1.0f,
    12,
    {
      { 0.0000f, 255 },  // C
      { 0.0833f, 16 },   // C#
      { 0.1667f, 96 },   // D
      { 0.2500f, 128 },  // Eb
      { 0.3333f, 8 },    // E
      { 0.4167f, 64 },   // F
      { 0.5000f, 4 },    // F#
      { 0.5833f, 192 },  // G
      { 0.6667f, 96 },   // G#
      { 0.7500f, 16 },   // A
      { 0.8333f, 128 },  // Bb
      { 0.9167f, 16 },   // B
    }
  },
  
  // Pentatonic
  {
    1.0f,
    12,
    {
      { 0.0000f, 255 },  // C
      { 0.0833f, 4 },    // C#
      { 0.1667f, 96 },   // D
      { 0.2500f, 4 },    // Eb
      { 0.3333f, 4 },    // E
      { 0.4167f, 140 },  // F
      { 0.5000f, 4 },    // F#
      { 0.5833f, 192 },  // G
      { 0.6667f, 4 },    // G#
      { 0.7500f, 96 },   // A
      { 0.8333f, 4 },    // Bb
      { 0.9167f, 4 },    // B
    }
  },
  
  // Pelog
  {
    1.0f,
    7,
    {
      { 0.0000f, 255 },  // C
      { 0.1275f, 128 },  // Db+
      { 0.2625f, 32 },  // Eb-
      { 0.4600f, 8 },    // F#-
      { 0.5883f, 192 },  // G
      { 0.7067f, 64 },  // Ab
      { 0.8817f, 16 },    // Bb+
    }
  },
  
  // Raag Bhairav That
  {
    1.0f,
    12,
    {
      { 0.0000f, 255 }, // ** Sa
      { 0.0752f, 128 }, // ** Komal Re
      { 0.1699f, 4 },   //    Re
      { 0.2630f, 4 },   //    Komal Ga
      { 0.3219f, 128 }, // ** Ga
      { 0.4150f, 64 },  // ** Ma
      { 0.4918f, 4 },   //    Tivre Ma
      { 0.5850f, 192 }, // ** Pa
      { 0.6601f, 64 },  // ** Komal Dha
      { 0.7549f, 4 },   //    Dha
      { 0.8479f, 4 },   //    Komal Ni
      { 0.9069f, 64 },  // ** Ni
    }
  },
  
  // Raag Shri
  {
    1.0f,
    12,
    {
      { 0.0000f, 255 }, // ** Sa
      { 0.0752f, 4 },   //    Komal Re
      { 0.1699f, 128 }, // ** Re
      { 0.2630f, 64 },  // ** Komal Ga
      { 0.3219f, 4 },   //    Ga
      { 0.4150f, 128 }, // ** Ma
      { 0.4918f, 4 },   //    Tivre Ma
      { 0.5850f, 192 }, // ** Pa
      { 0.6601f, 4 },   //    Komal Dha
      { 0.7549f, 64 },  // ** Dha
      { 0.8479f, 128 }, // ** Komal Ni
      { 0.9069f, 4 },   //    Ni
    }
  },
};

#define FIX_OUTLIER(destination, expected_value) if (fabsf(destination / expected_value - 1.0f) > 0.1f) { destination = expected_value; }

void Settings::ResetScale(int i) {
  persistent_data_.scale[i] = preset_scales[i];
}


void Settings::Init() {
  freshly_baked_ = false;
  

  // Set default values for all calibration and state settings.
  // This settings will be written to flash memory the first time the module
  // is powered on, or if corrupted data is found in the flash sector,
  // following a major firmware upgrade.
  CalibrationData& c = persistent_data_.calibration_data;
  fill(&c.adc_scale[0], &c.adc_scale[ADC_CHANNEL_LAST], -2.0f);
  fill(&c.adc_offset[0], &c.adc_offset[ADC_CHANNEL_LAST], +1.0f);
  fill(&c.dac_scale[0], &c.dac_scale[DAC_CHANNEL_LAST], -6212.8f);
  fill(&c.dac_offset[0], &c.dac_offset[DAC_CHANNEL_LAST], 32768.0f);
  c.adc_offset[ADC_CHANNEL_T_RATE] = 60.0f;
  c.adc_scale[ADC_CHANNEL_T_RATE] = -120.0f;
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

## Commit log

2018-10-25 Add files via upload
    Marbles calibration file and spreadsheet for my particular modules
    [Marbles_calibration.xls]
2021-03-02 Add supervisor, move recom
    [AJH_sup_marbles_v70.brd, AJH_sup_marbles_v70.sch]
